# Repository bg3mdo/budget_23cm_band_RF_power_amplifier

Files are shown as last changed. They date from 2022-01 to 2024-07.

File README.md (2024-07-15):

# Budget MRFE6S9160 LDMOS Transistor 23cm band 1.3GHz 150 Watt Solid State Power Amplifier (SSPA)

This project is under CC-BY-SA 4.0, please follow the license.

MRFE6S9160 (E is an enhanced version of MRF6S9160, but there is no difference for the RF matching and general performance) is commonly found in many old GSM base-station systems and used as a final stage power amplifier (PA) device. We have seen there are already many excellent 23cm band 1.3GHz PAs built with this transistor. The one designed by DF9IC is very popular.  

MRFE6S9160 is easy to get from the Asian market, usually sold as a second-hand component, where they are removed from used base stations. That means this LDMOS transistor is super cheap compared to many other similar devices. However, there are some issues, for example, this device comes without many documents, S-parameter information and simulation models. Therefore, this makes computer-aided design is more difficult on this device.

MRFE6S9160 can be used for making a budget 23cm band PA and for an EME project. After a few design iterations, I have made the FR4 substrate 23cm band MRFE6S9160 PA, and decided to open-source it. The board can be fabricated by JLC 0.8mm 1zo technology.

I have learnt a lot from this project, including high power RF related knowledge and the use of design/simulation tools.

DF9IC has made a FR4 substrate experiment, but the result was not grate. I started from there, and further analysing his work. I considered there were rooms to improve, and FR4 would be still a solution for 23cm band PA designs. After playing with computer simulations, I decided to change the layout, so making rooms for better matching. 

The following pictures show the new layout:

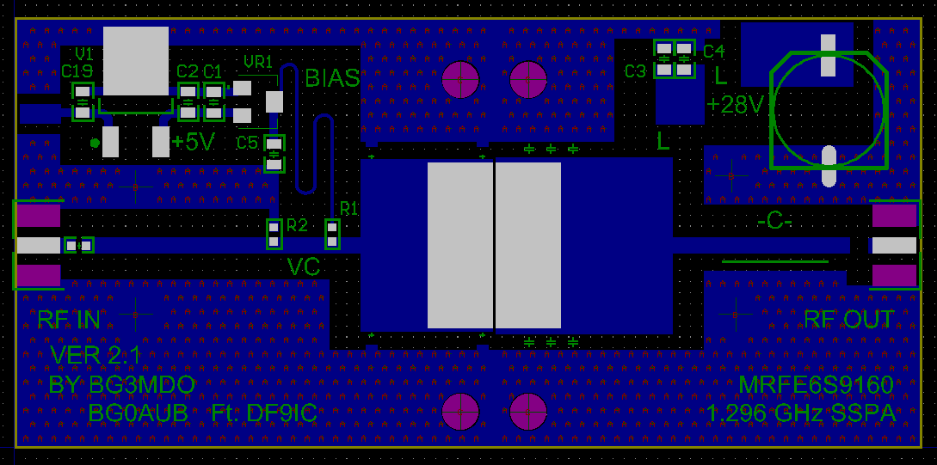
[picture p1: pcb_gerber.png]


&nbsp;

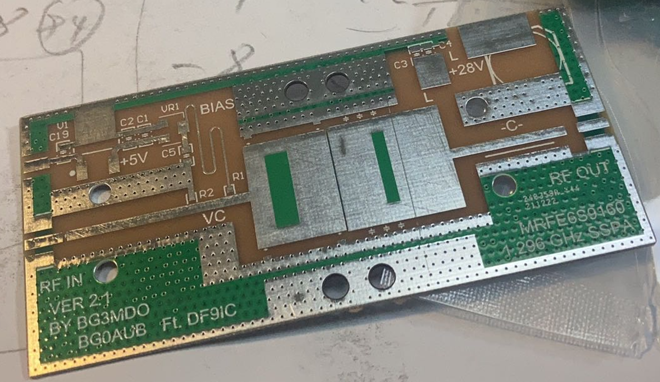
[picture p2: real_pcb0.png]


PA 3D look (Specially thanks to BG7GBC for the generation of 3D picture):

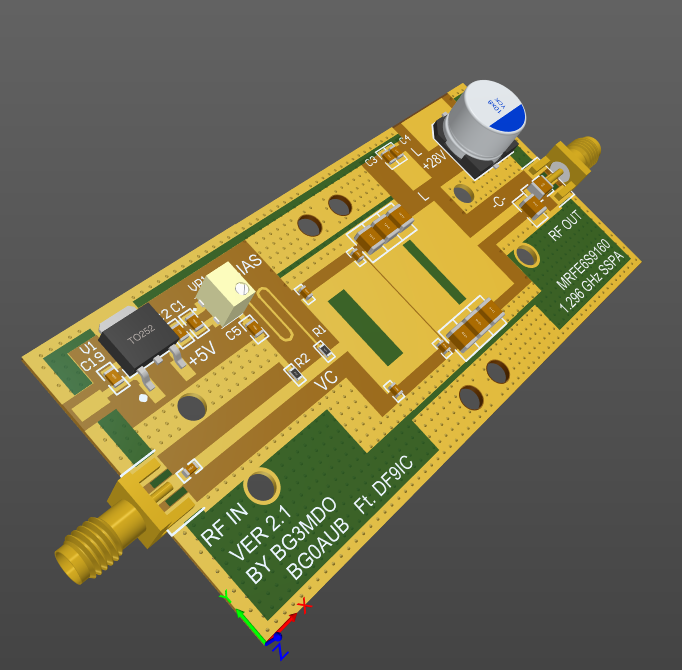
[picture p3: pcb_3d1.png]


&nbsp;

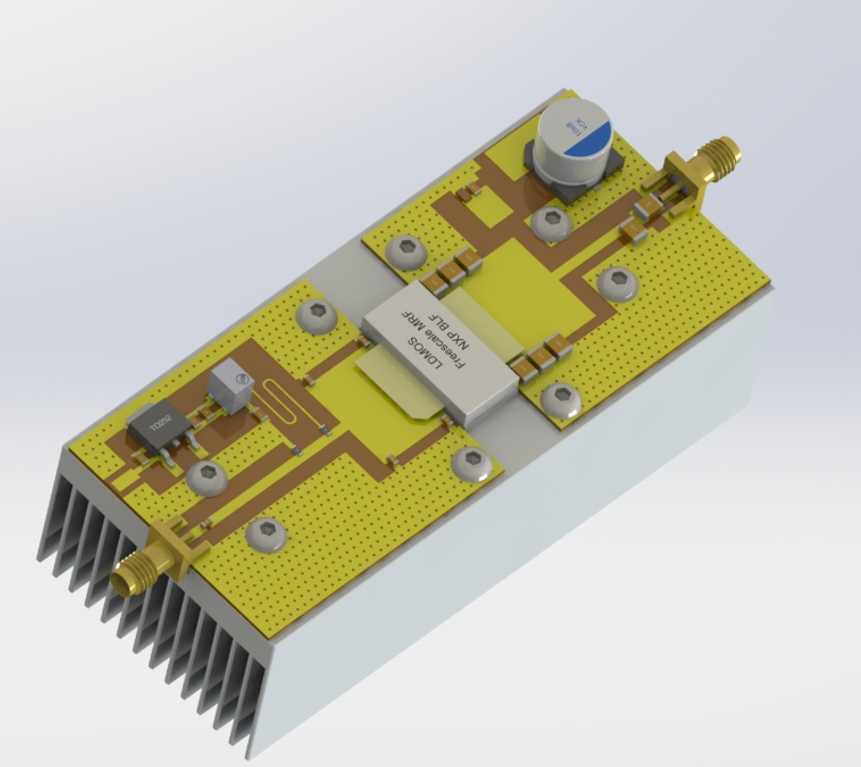
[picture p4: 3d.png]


&nbsp;

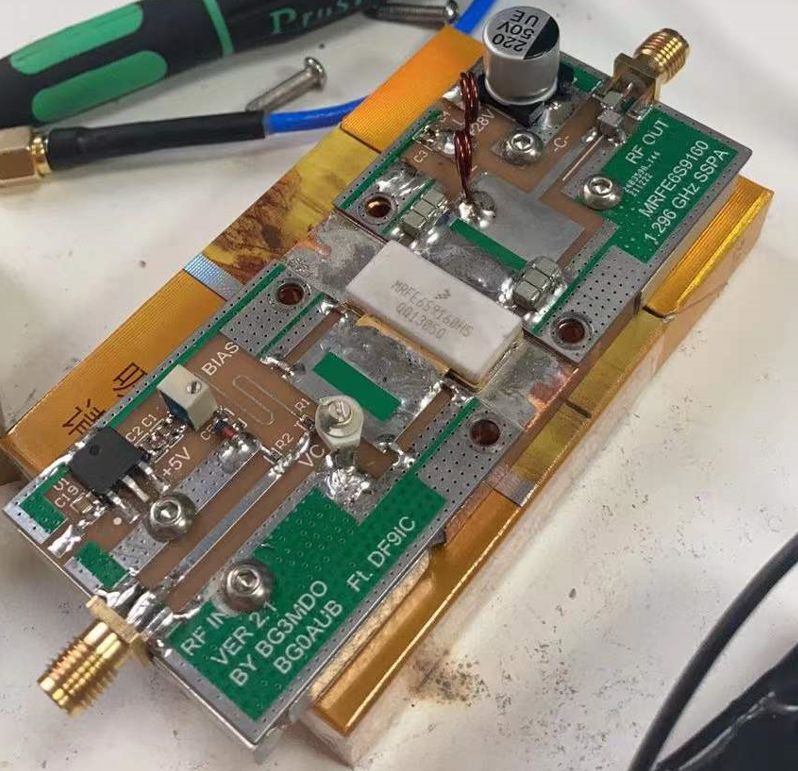
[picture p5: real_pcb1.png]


The PCB needs to be cut into two halves to create the space for LDMOS.

The installation process should be straightforward, and tuning process is not complex. In older to test this PA, a 28V 20A PSU is needed. Overcurrent protection one is more expected. After the solder process, the PA should be looking like as follows:

Note that the PA will produce massive heats, so a good heatsink should be given. LDMOS quiescent current is sensitive to temperature. The bias circuit can be upgrade to temperature compensation ones as well. Our dual LDMOS power combined PA has replaced the simple biased circuit with an enhanced one.

## BOM and Assembly

BOM table as follows:

|Component|Name|Package|Quantity|
|:----:|:----:|:----:|:----:|
|1uF 50V|MLCC Capacitor|C 0805|2|
|1nF 50V|MLCC Capacitor|C 0805|3|
|10nF 50V|MLCC Capacitor|C 0805|1
|100pF 100V|C0G Capacitor|C 0603|1
|3.3pF 100V|C0G Capacitor|C 0603|2
|4.7pF 100V|C0G Capacitor|C 0603|2
|100pF 500V|ATC500B Capacitor|C 1210|1
|3.3pF 100V|ATC500B Capacitor|C 1210|6
|2.2pF 500V|ATC500B Capacitor|C 1210|1
|100uF/50V|Aluminum Electrolytic Capacitor|CT 10*8-C|1
|SMA|SMA Female Connector|SMA-KE|2
|MRFE6S9160|N-CHANNEL RF LDMOS|MRFE6S9160HR3/HSR3|1|
|51R|Chip Resistor|R 0603|1|
|2K2|Chip Resistor|R 0603|1|
|LM7808/05|Regulator|TO252|1|
|3224W-1-103E|10K Variable Resistor|3224W1205E|1|
|3pF Variable Cap|High Q Cap Trimmer|3P-6mm|1|

Schematic of the PA:

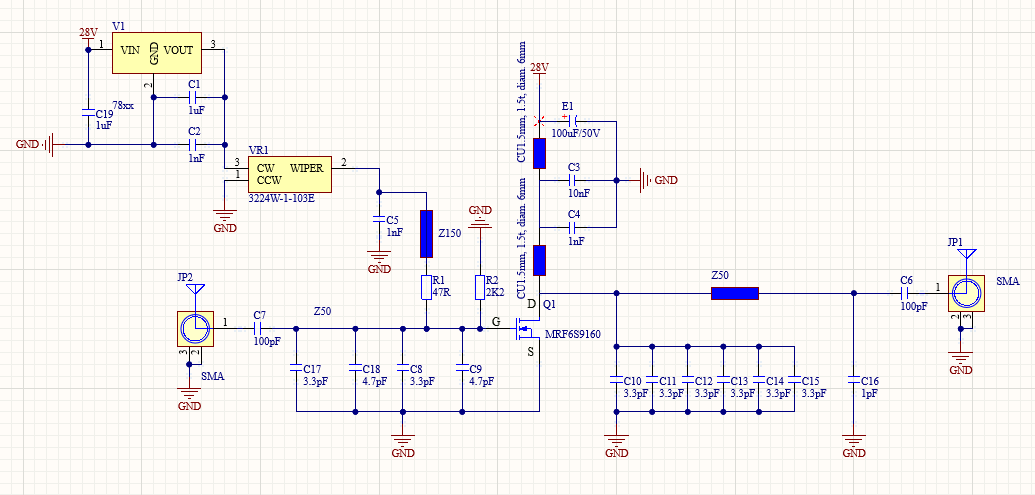
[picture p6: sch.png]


Assembly:

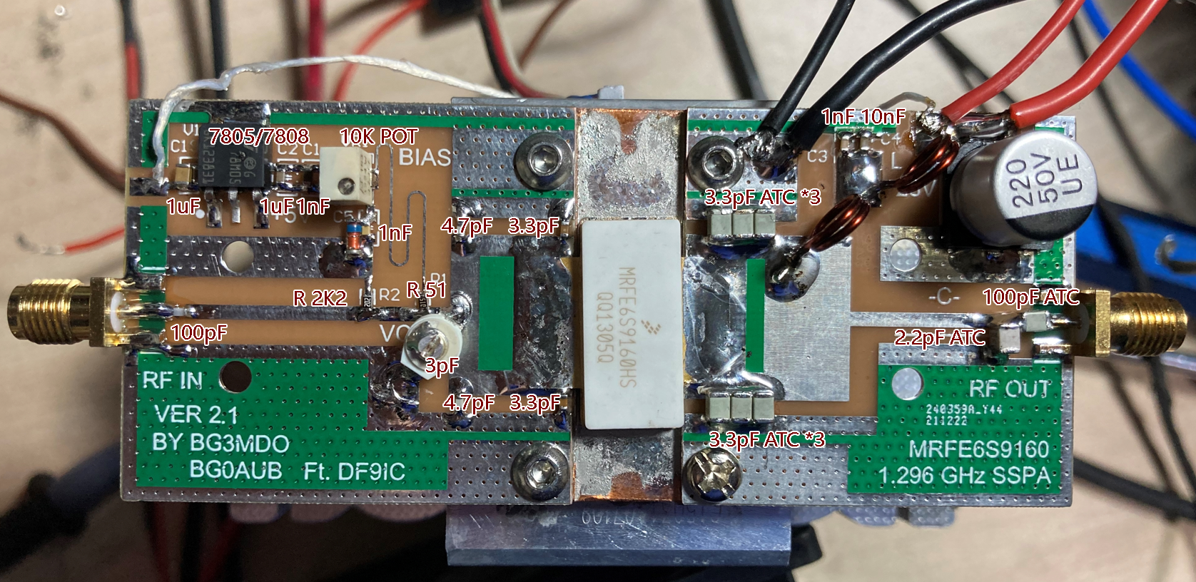
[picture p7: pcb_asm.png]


R1 can be 47 or 51 Ohm, two coils are 1.5mm thick enameled wire, 1.5T on a 6mm drill bit.

## Turning procedure:

**VERY IMPORTANT**, BEFORE STARTED, MAKE SURE your ground wires and PA board ground are connected properly and firmly.

- Make sure the bias pot is at minimum settings - low voltage applying to LDMOS gate!

- Setting the bias pot, voltage, we should set the LDMOS at 1.3A quiescent current (Id). 

- The positions of six 3.3pF ATC capacitors should be mounted to the PCB silk screen indicated locations.

- For the input side, the 3pF variable capacitor turning is needed. A better input matching can be then obtained – input VSWR (S11) should be < 1.5.

- Generally saying, when the input is around 2 Watts, the PA will consume around 8A current and output > 60 Watts. In this case, some fine tuning can be performed – moving upper/lower three ATC capacitors together left or right 1mm each time in order to obtain the maximum output.

- Large signal gain of this PA is around 16-17 dB. If the PA current is under 7A where input is 2W, or even less, you will need to move these 3.3 pF left/right harshly, 2mm for example, and try to find a point that you have a good current reading. Some bad ATC capacitor will cause the low current/power issue too, so you should consider to replace these capacitors in the case no proper power generated. A large current is a good sight of outputting expected power.

- When the input power around 6W, you should see the output is nearly saturated – output compressed. 

- Excessive solder is not recommended for any pads, including LDMOS gate and drain pads. 

## Some Results:

There are some testing results, we know the board and LDMOS have variations, but, generally saying, based on a few builds, the output power level and gain of this design is stable. One of the testing results (Id = 1.3A and Vcc = 28V):

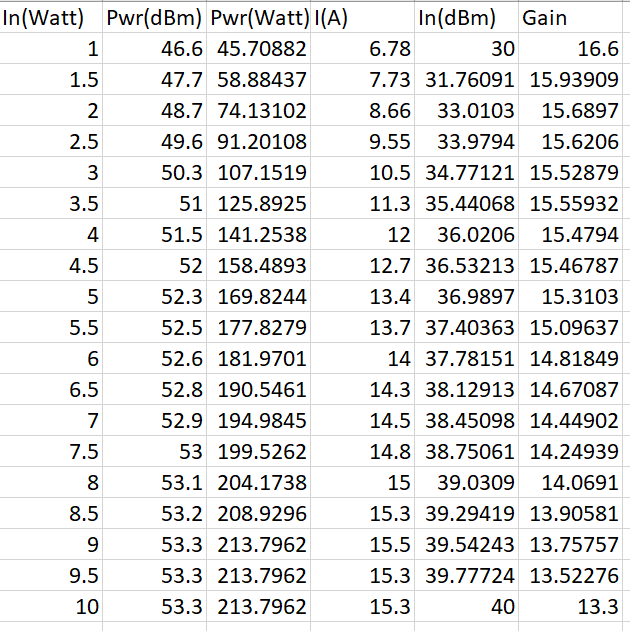
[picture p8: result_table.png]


A plot of the output power and current:

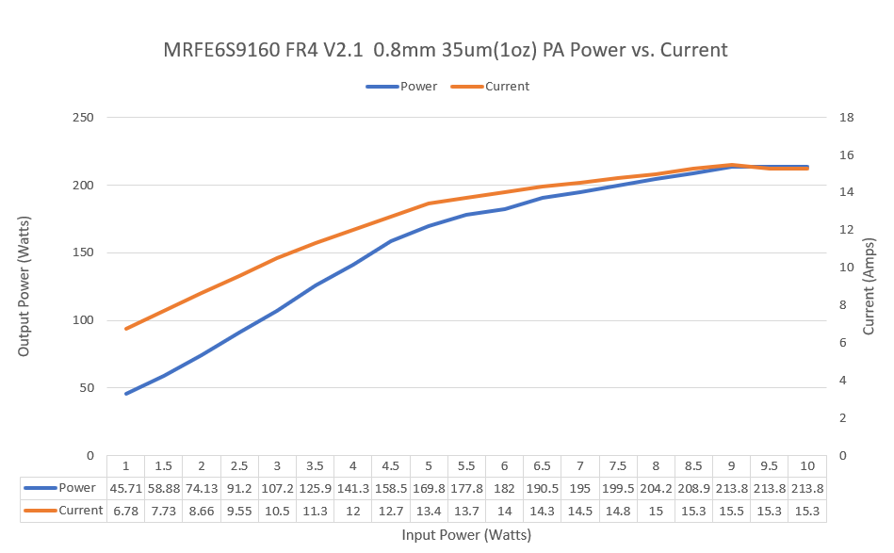
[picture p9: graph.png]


## Duo LDMOS Version:

Typically, the above design encounters a draft bias issue, causing changes in the working conditions as the PA heats up. This issue is exacerbated when used in an outdoor setup, such as placing the PA close to your dish for most EME operations. Additionally, a small dish (3-4 meters in diameter) requires more power. To address this, a power combined version using 4x LDMOS is recommended. You will need another coupler to combine the power from both units, as PCB-based power combiners cannot handle such high power levels. I suggest using coax cable to make power combiners. 

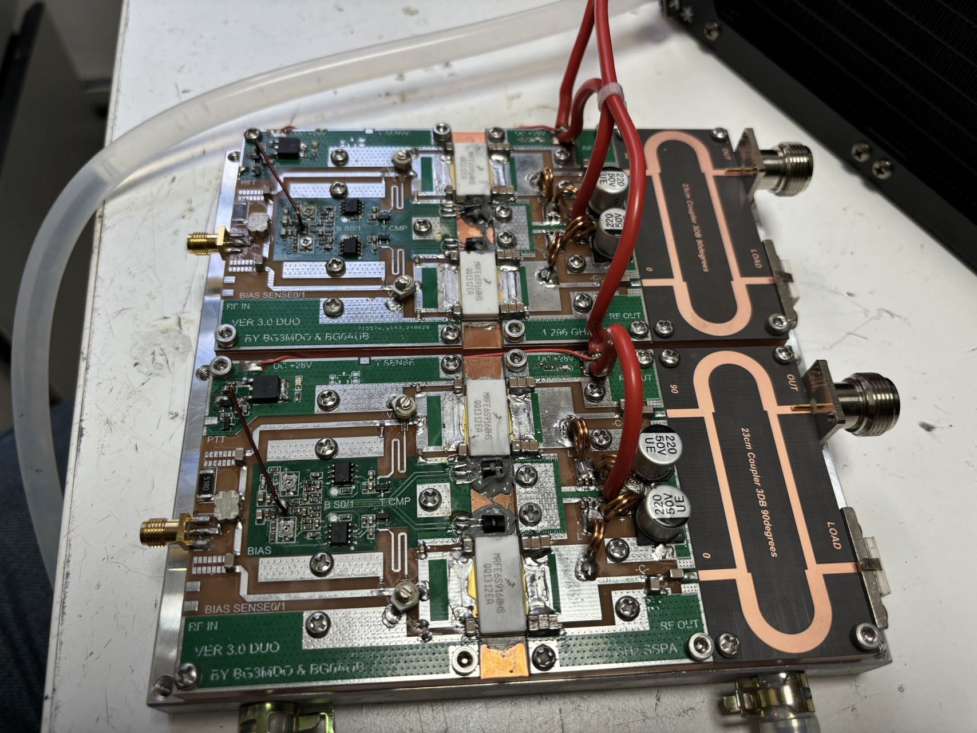
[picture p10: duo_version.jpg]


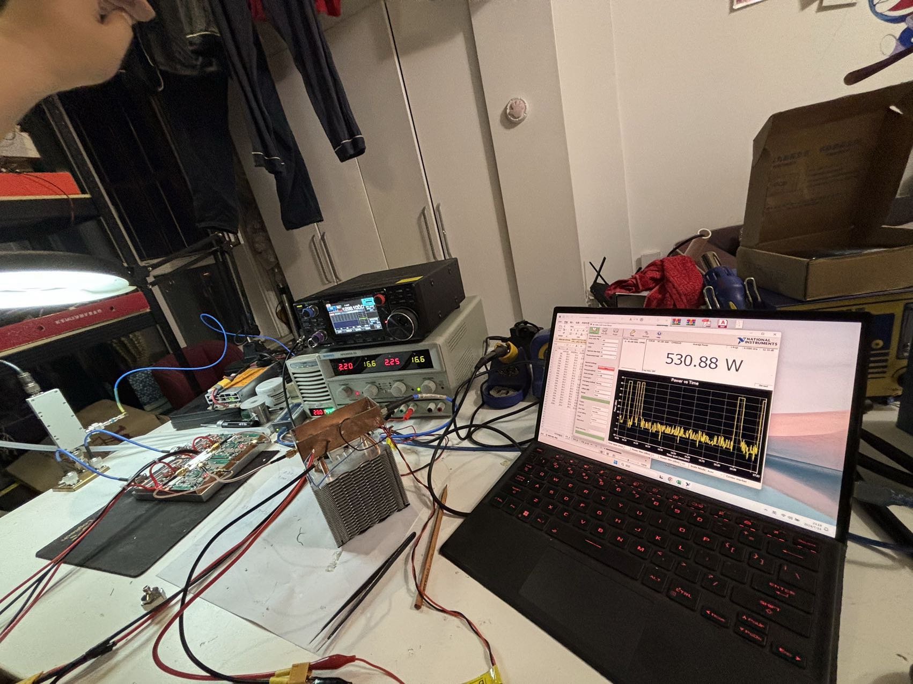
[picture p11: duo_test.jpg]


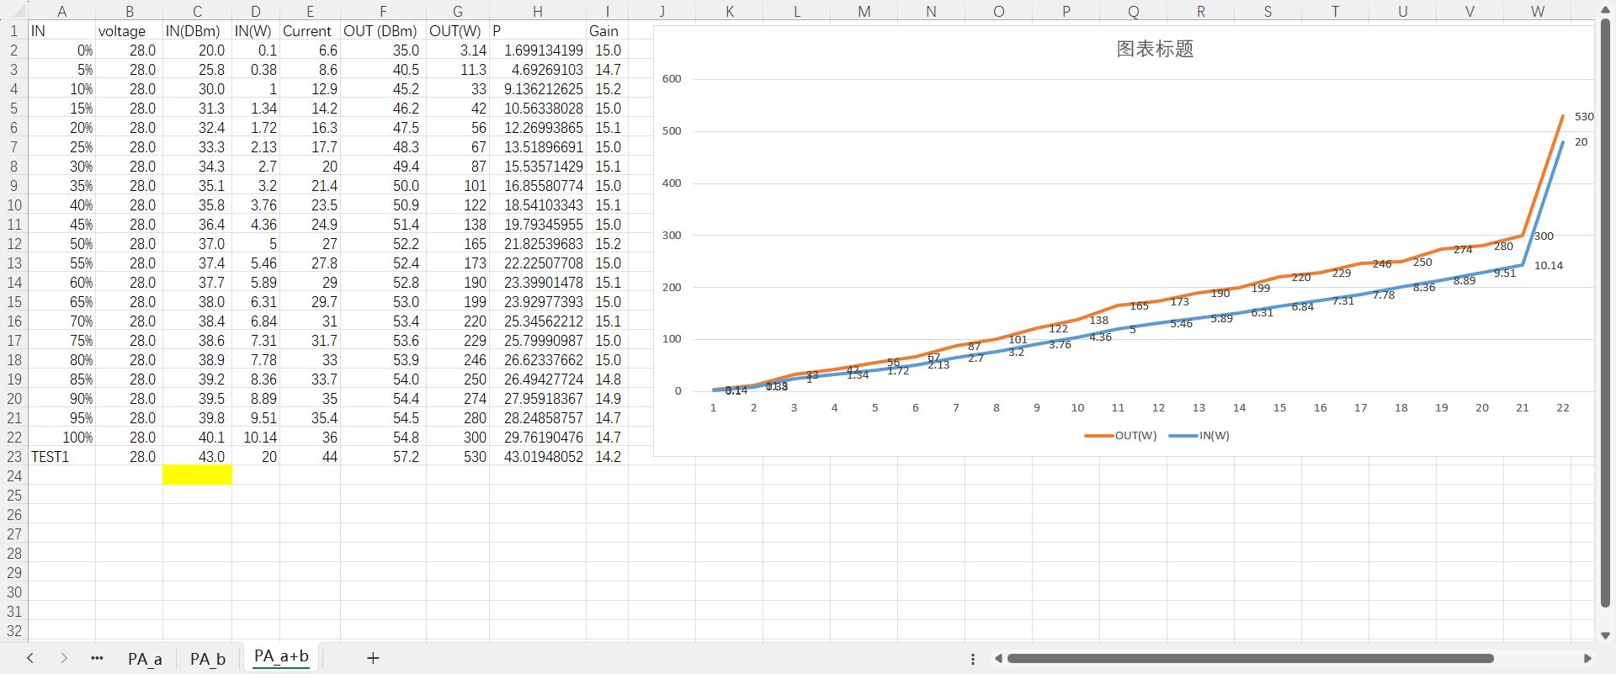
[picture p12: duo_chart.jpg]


VY 73!

BG3MDO (Yuan) and BG0AUB (Feng)

CC BY-SA 4.0

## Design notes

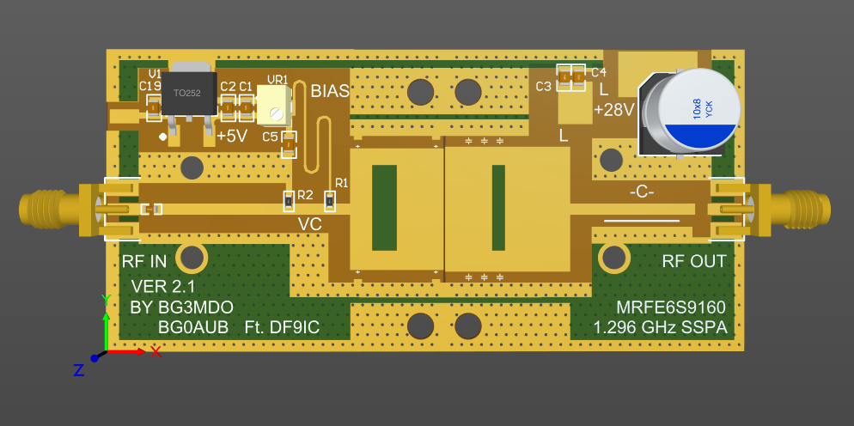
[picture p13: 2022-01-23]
pcb_3d0.png

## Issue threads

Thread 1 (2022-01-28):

RF output connector

g4ixt, 2022-01-28:
Have you tried using an N-type connector on the output?  That's a lot of power at 1.3GHz to be going through an SMA connector (although within the rating for good quality ones).  For your double transistor board (that I saw on Twitter you are working on), it will be very near the maximum power handling of the SMA connector.

For your hybrid combiner (on Twitter) you could perhaps fit a diode detector at the ballast load port, so that if there is a power imbalance or phase error you can give an indication or logic "trip" to save blowing it up.

I am going to try building one of these and have ordered some transistors via ali.

73 de G4IXT

bg3mdo, 2022-01-29:
Dear Ian,

Thanks for your email!

For the output, we did try the N-type connector. N-type connector is much
better than SMA for large power handling. For the double transistor one,
the output SMA is for testing purposes - tuning each PA. After done the
tuning, the SAM connector will be removed from the board, and feeding the
output directly into an FR4 substrate coupler.

We have fit two directional couplers at the output side of the branch line
coupler to monitor the imbalance. We have made the following 30dB cable
coupler - milling two cables and solder together:

[image: dcoupler.png]

The transistor is cheaper enough, hope you have fun with the building
process!

VY 73.

Cheers,
BG3MDO Yuan

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

bg3mdo, 2022-01-29:
Feeding in an F4B coupler, sorry it is not FR4.

Cheers,
Yuan

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

Closed 2022-05-04.

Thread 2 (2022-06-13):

100V chip capacitors

g4ixt, 2022-06-13:
It is hard to find 100V 0603 NP0/C0G capacitors in small quantities, for C17, C18, C8, C9.  I can get 50V ones, or in 0805 package can get 100V ones.  Would the larger size of 0805 be a problem at that part of the circuit?

Could you provide some details of how you fixed the transistors?  I am thinking of using low temperature 137C Sn/Bi solder paste and a temperature controlled hotplate to solder them onto a copper plate the size of the two half boards and transistor, bolted to a larger heatsink.

I would also be interested to know the dimensions of heatsink you used.  I bought two transistors so will build two amplifiers in the hope that one of them will work.  If both work I might build a combiner, but at the moment I can only generate 1W of drive power so I will also need a driver amplifier.

dh2wq, 2022-09-13:
@g4ixt 50V types should be fine at the input. You may have look on DF9IC presentation regarding soldering. He uses Sn42Bi58 Paste. (http://www.df9ic.de/doc/2015/mmrt_2015/mmrt_2015_1296MHz_PAs.pdf)

@bg3mdo can you please provide the Altium Sources? I haven‘t built a pa on this power at 23cm or above and I would like to test some modifications to gain more experience.

Closed 2022-12-01.

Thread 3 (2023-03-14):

Dual Version

9H1LO, 2023-03-14:
Very nice project, how is the progress with the dual ldmos version ?

bg3mdo, 2023-03-15:
I will update it soon

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

9H1LO, 2023-03-31:
many thanks looking forward to this

wb0gaz, 2023-10-01:
Also interested dual LDMOS version!

wb0gaz, 2024-08-11:
Also interested in multi-device QRO version, open source (gerbers) or other way. Thank you to BG3MDO for nice innovation.

9H1LO, 2025-05-20:
any updates on publishing or it is a dead project ?

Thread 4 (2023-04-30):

Diode across C5

9H1LO, 2023-04-30:
is that a MELF Diode across C5 ? maybe a zener ?

bg3mdo, 2023-05-04:
Hi 9H1LO, yes, but that has been removed from the final version, was there to be a protection use.

9H1LO, 2023-05-06:
ok thanks why not keep it there ? also i notice the electrolytic is 100uF in the BOM and 220uF on the build

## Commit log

2022-01-23 adding files
    [mrfe6s9160pa.xlsx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]
2022-01-23 remove useless files
    [mrfe6s9160pa.xlsx]
2022-01-23 Error correction and update - update BOM and pcb_asm.png with better quality one.
